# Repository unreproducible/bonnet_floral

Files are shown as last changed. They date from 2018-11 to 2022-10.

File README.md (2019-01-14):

Floral Bonnet

This is an IoT-ish style Bonnet (Hat) intended for a Raspberry Pi Zero based board.

Obviously you can use it on anything with the appropriate header.

Includes:
* BME280 - I2C
* TSL2561 - I2C
* 128x64 OLED Screen - SPI
* RGB LED - 3xGPIO/PWM
* User Button - GPIO
* Serial Port for Kernel Debugging

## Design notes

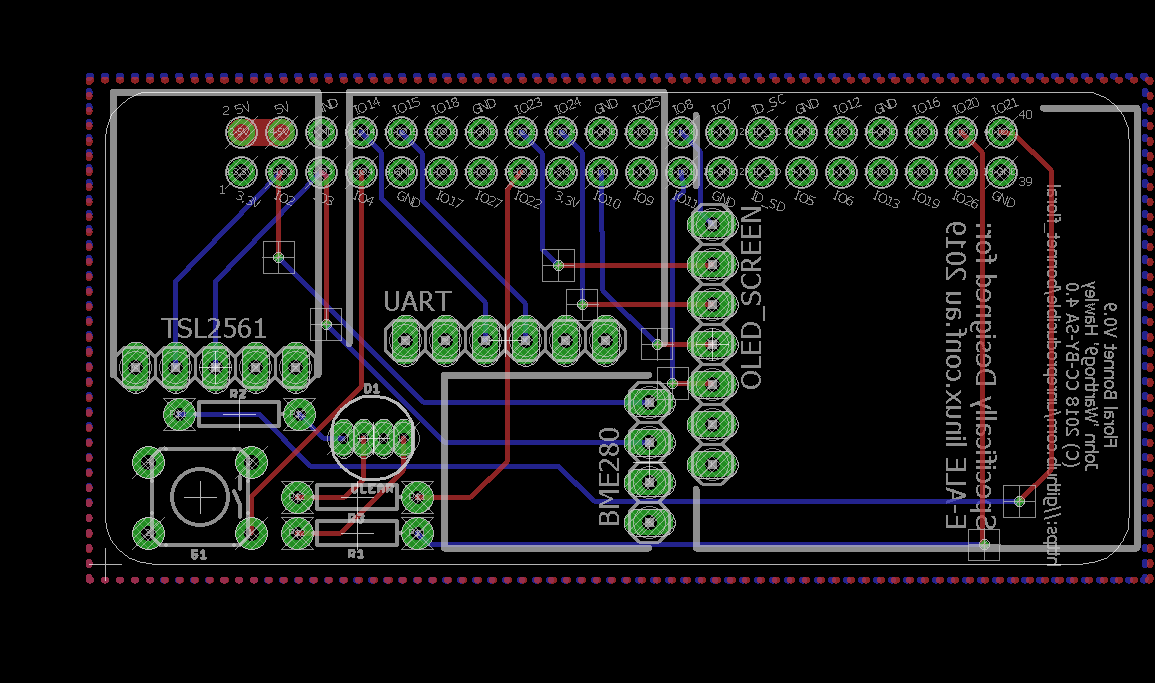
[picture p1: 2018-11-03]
bonnet_floral.png

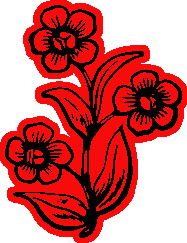
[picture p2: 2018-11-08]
artwork/floral.bmp

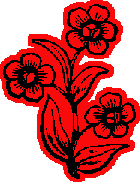
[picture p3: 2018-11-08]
artwork/floral_mirror_smaller.bmp

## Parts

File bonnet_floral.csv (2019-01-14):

Part | Qty | Value | Device | Package | Description | PROD_ID | SF_SKU | VALUE | Expected Cost | Link to example:
BME280 | 1 |  | BME280 subassembly | BME280 subassembly | BME280 subassembly |  |  |  | $4.50 | https://www.alibaba.com/product-detail/3In1-BME280-Digital-Temperature-Humidity-Barometric_60760099302.html
D1 | 1 | CLEAR | LED-RGB-CCCLEAR | LED-RGB-THRU@1 | LED-RGB Common Cathode | DIO-08418 |  | CLEAR | 1.02 | https://www.digikey.com/product-detail/en/inolux/HV-5RGB25/1830-1015-ND/7604615
IC1 |  | RASPBERRY_PI_ZERO_W_(V1.3)-WOUT-RUNTVNOMOUNT | RASPBERRY_PI_ZERO_W_(V1.3)-WOUT-RUNTVNOMOUNT | RASPBERRYPIZEROWV13-WOUT-RUNTV-NOMOUNT | Raspberry Pi Zero W (v1.3) Single-board Computers (installed on back of board) |  |  |  | 1.15 | https://www.digikey.com/product-detail/en/sullins-connector-solutions/SFH11-PBPC-D10-ST-BK/S9197-ND/1990090
OLED_SCREEN |  |  | 0.96in SPI OLED subassembly | 0.96in SPI OLED subassembly | 0.96in SPI OLED subassembly |  |  |  | 3.48 | https://www.alibaba.com/product-detail/SPI-IIC-interface-SSD1306-micro-oled_60581789872.html
R1 |  |  | RESISTORAXIAL-0.3 – 100 Ohm | AXIAL-0.3 | Generic Resistor Package |  |  |  | $0.01 | Note: Whatever is close, and cheap is fine (120Ohm would work)
R2 |  |  | RESISTORAXIAL-0.3 – 150 Ohm | AXIAL-0.3 | Generic Resistor Package |  |  |  | $0.01 | Note: Whatever is close, and cheap is fine (200Ohm would work)
R3 |  |  | RESISTORAXIAL-0.3 – 150 Ohm | AXIAL-0.3 | Generic Resistor Package |  |  |  | $0.01 | Note: Whatever is close, and cheap is fine (200Ohm would work)
S1 |  | MOMENTARY-SWITCH-SPST-PTH-6.0MM | MOMENTARY-SWITCH-SPST-PTH-6.0MM | TACTILE_SWITCH_PTH_6.0MM | Momentary Switch (Pushbutton) - SPST | SWCH-08441 | COM-00097 |  | 0.11 | https://www.digikey.com/product-detail/en/te-connectivity-alcoswitch-switches/1825910-6/450-1650-ND/1632536
TSL2561 |  |  | TSL2561 subassembly | TSL2561 subassembly | TSL2561 subassembly |  |  |  | 1.1 | https://www.alibaba.com/product-detail/GY-2561-TSL2561-Light-Intensity-Luminosity_60419642969.html?s=p
UART |  |  | CP2102 subassembly | CP2102 subassembly | CP2102 subassembly |  |  |  | 1.01 | https://www.alibaba.com/product-detail/6Pin-Serial-Converter-UART-STC-CP2102_60768471247.html?s=p
 |  |  |  |  |  |  | Total per board (parts): |  | 12.40708
 |  |  |  |  |  |  | Rough assembly costs: |  | 3.8
 |  |  |  |  |  |  | Shipping to US |  | 0.32
 |  |  |  |  |  |  | Rough total cost: |  | 16.52708

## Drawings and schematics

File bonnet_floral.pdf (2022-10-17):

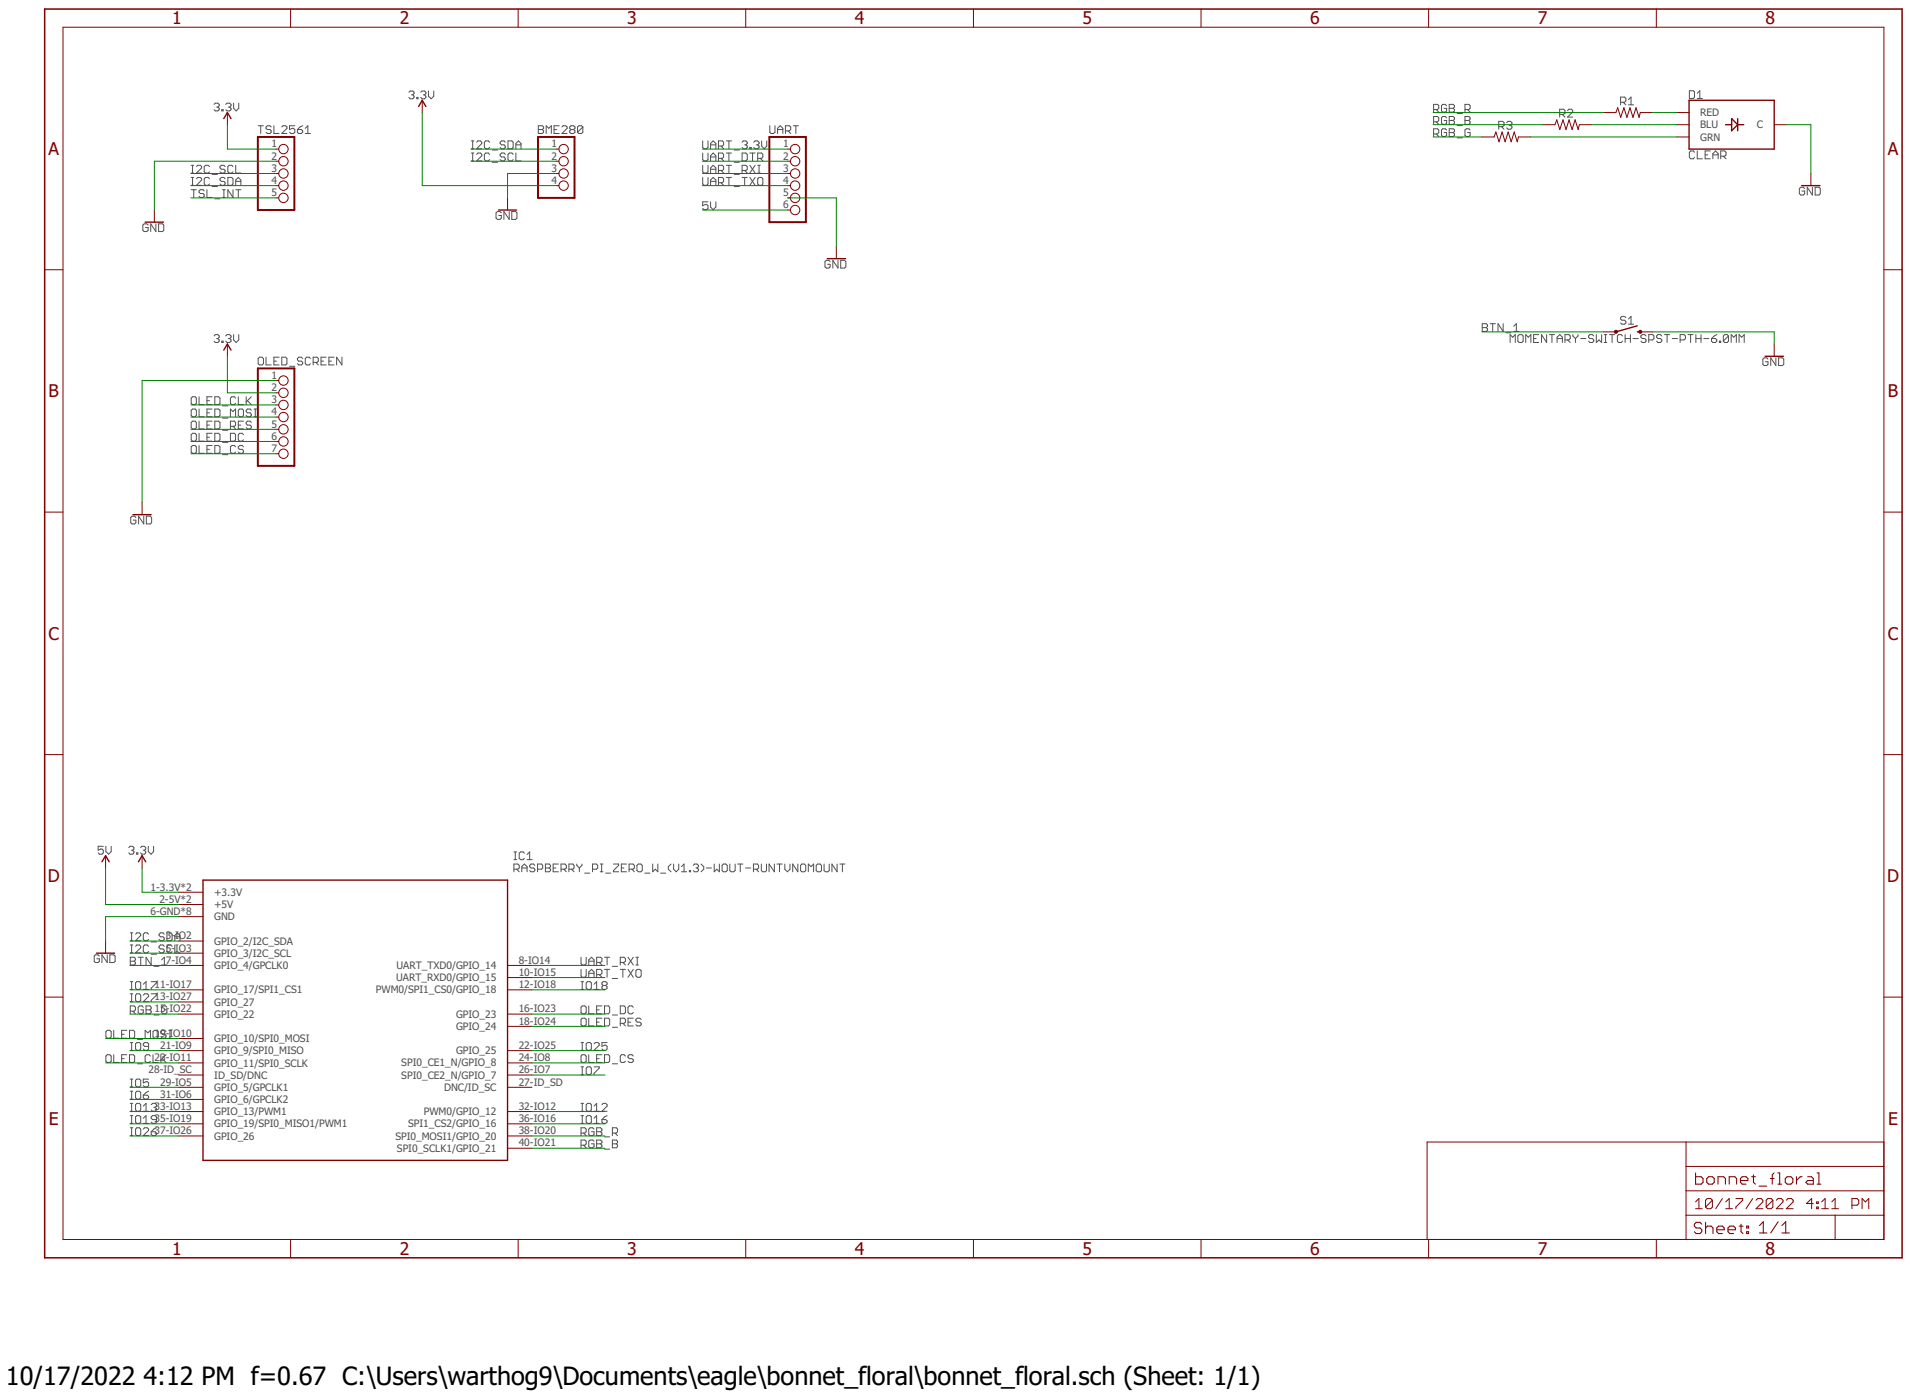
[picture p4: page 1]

10/17/2022 4:12 PM f=0.67 C:\Users\warthog9\Documents\eagle\bonnet_floral\bonnet_floral.sch (Sheet: 1/1)

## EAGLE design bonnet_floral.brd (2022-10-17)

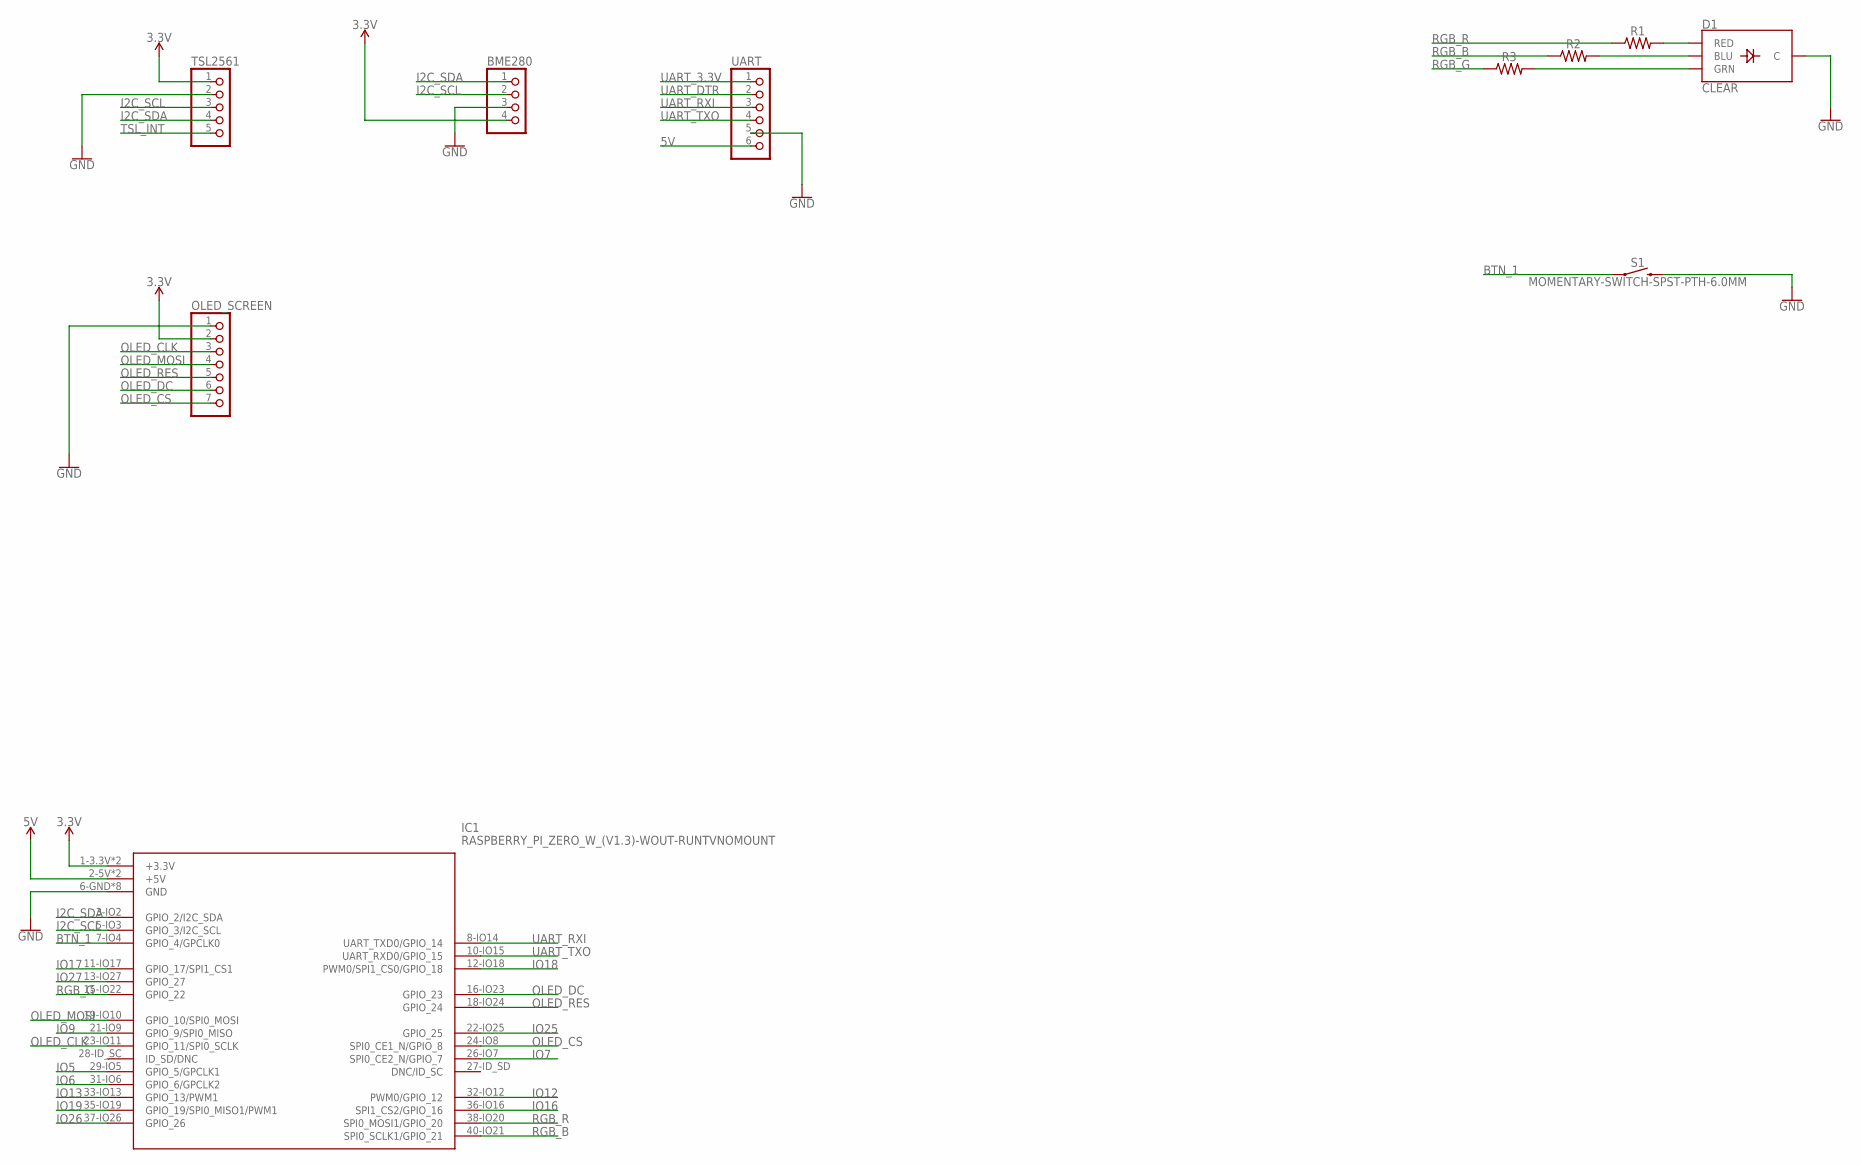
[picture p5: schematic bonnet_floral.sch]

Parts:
BME280: PINHD-1X4; 1X04
D1: CLEAR; LED-RGB-THRU@1
IC1: RASPBERRY_PI_ZERO_W_(V1.3)-WOUT-RUNTVNOMOUNT; RASPBERRYPIZEROWV13-WOUT-RUNTV-NOMOUNT
OLED_SCREEN: PINHD-1X7; 1X07
R1, R2, R3: AXIAL-0.3
S1: MOMENTARY-SWITCH-SPST-PTH-6.0MM; TACTILE_SWITCH_PTH_6.0MM
TSL2561: PINHD-1X5; 1X05
UART: PINHD-1X6; 1X06

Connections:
3.3V: BME280.4, IC1.1-3.3V (+3.3V), IC1.17-3.3V (+3.3V), OLED_SCREEN.2, TSL2561.1
5V: IC1.2-5V (+5V), IC1.4-5V (+5V), UART.6
BTN_1: IC1.7-IO4 (GPIO_4/GPCLK0), S1.1
GND: BME280.3, D1.2 (C), IC1.6-GND (GND), IC1.9-GND (GND), IC1.14-GND (GND), IC1.20-GND (GND), IC1.25-GND (GND), IC1.30-GND (GND), IC1.34-GND (GND), IC1.39-GND (GND), OLED_SCREEN.1, S1.3 (2), TSL2561.2, UART.5
I2C_SCL: BME280.2, IC1.5-IO3 (GPIO_3/I2C_SCL), TSL2561.3
I2C_SDA: BME280.1, IC1.3-IO2 (GPIO_2/I2C_SDA), TSL2561.4
IO5: IC1.29-IO5 (GPIO_5/GPCLK1)
IO6: IC1.31-IO6 (GPIO_6/GPCLK2)
IO7: IC1.26-IO7 (SPI0_CE2_N/GPIO_7)
IO9: IC1.21-IO9 (GPIO_9/SPI0_MISO)
IO12: IC1.32-IO12 (PWM0/GPIO_12)
IO13: IC1.33-IO13 (GPIO_13/PWM1)
IO16: IC1.36-IO16 (SPI1_CS2/GPIO_16)
IO17: IC1.11-IO17 (GPIO_17/SPI1_CS1)
IO18: IC1.12-IO18 (PWM0/SPI1_CS0/GPIO_18)
IO19: IC1.35-IO19 (GPIO_19/SPI0_MISO1/PWM1)
IO25: IC1.22-IO25 (GPIO_25)
IO26: IC1.37-IO26 (GPIO_26)
IO27: IC1.13-IO27 (GPIO_27)
unnamed: D1.1 (RED), R1.P$2 (2)
unnamed: D1.4 (BLU), R2.P$2 (2)
unnamed: D1.3 (GRN), R3.P$2 (2)
OLED_CLK: IC1.23-IO11 (GPIO_11/SPI0_SCLK), OLED_SCREEN.3
OLED_CS: IC1.24-IO8 (SPI0_CE1_N/GPIO_8), OLED_SCREEN.7
OLED_DC: IC1.16-IO23 (GPIO_23), OLED_SCREEN.6
OLED_MOSI: IC1.19-IO10 (GPIO_10/SPI0_MOSI), OLED_SCREEN.4
OLED_RES: IC1.18-IO24 (GPIO_24), OLED_SCREEN.5
RGB_B: IC1.40-IO21 (SPI0_SCLK1/GPIO_21), R2.P$1 (1)
RGB_G: IC1.15-IO22 (GPIO_22), R3.P$1 (1)
RGB_R: IC1.38-IO20 (SPI0_MOSI1/GPIO_20), R1.P$1 (1)
TSL_INT: TSL2561.5
UART_3.3V: UART.1
UART_DTR: UART.2
UART_RXI: IC1.8-IO14 (UART_TXD0/GPIO_14), UART.3
UART_TXO: IC1.10-IO15 (UART_RXD0/GPIO_15), UART.4

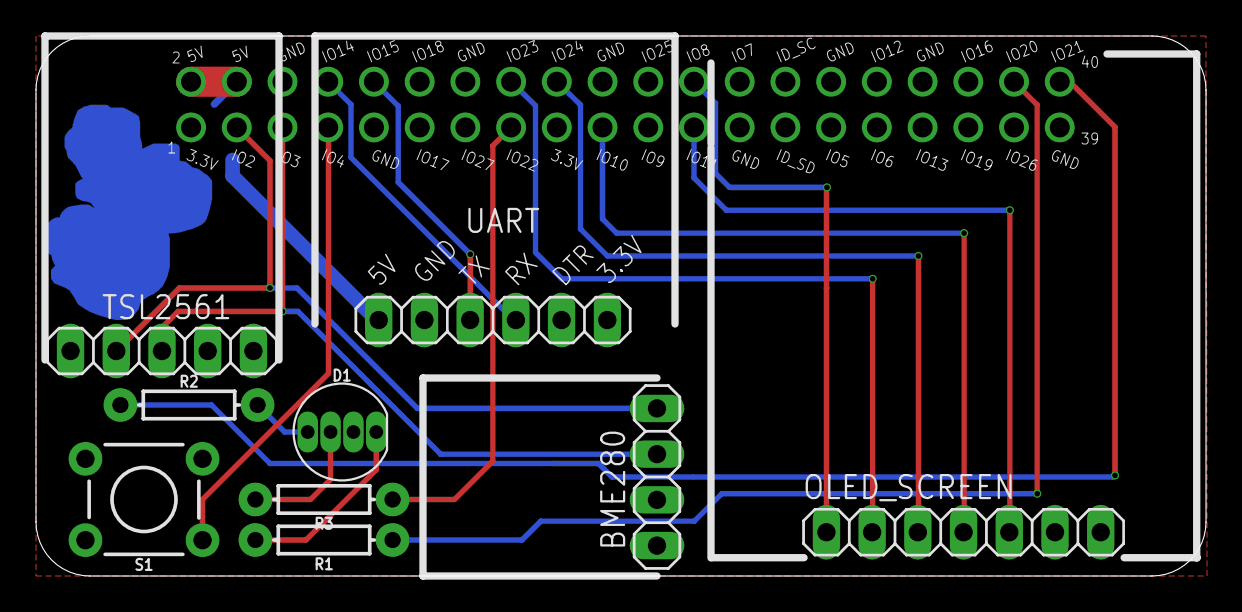
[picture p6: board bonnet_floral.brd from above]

Board: 2 copper layers, 65.0 x 30.0 mm, 11 parts (1 on the bottom side), 19 nets.

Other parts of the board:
U$1: FLORAL_SMALLER_MIRROR

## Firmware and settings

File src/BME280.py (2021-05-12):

# Distributed with a free-will license.
# Use it any way you want, profit or free, provided it fits in the licenses of its associated works.
# BME280
# This code is designed to work with the BME280_I2CS I2C Mini Module available from ControlEverything.com.
# https://www.controleverything.com/content/Humidity?sku=BME280_I2CS#tabs-0-product_tabset-2

# from https://github.com/ControlEverythingCommunity/BME280.git
# minor fixes to adjust for python3

import smbus
import time

# Get I2C bus
bus = smbus.SMBus(1)

# BME280 address, 0x76(118)
# Read data back from 0x88(136), 24 bytes
b1 = bus.read_i2c_block_data(0x76, 0x88, 24)

# Convert the data
# Temp coefficients
dig_T1 = b1[1] * 256 + b1[0]
dig_T2 = b1[3] * 256 + b1[2]
if dig_T2 > 32767 :
    dig_T2 -= 65536
dig_T3 = b1[5] * 256 + b1[4]
if dig_T3 > 32767 :
    dig_T3 -= 65536

# Pressure coefficients
dig_P1 = b1[7] * 256 + b1[6]
dig_P2 = b1[9] * 256 + b1[8]
if dig_P2 > 32767 :
    dig_P2 -= 65536
dig_P3 = b1[11] * 256 + b1[10]
if dig_P3 > 32767 :
    dig_P3 -= 65536
dig_P4 = b1[13] * 256 + b1[12]
if dig_P4 > 32767 :
    dig_P4 -= 65536
dig_P5 = b1[15] * 256 + b1[14]
if dig_P5 > 32767 :
    dig_P5 -= 65536
dig_P6 = b1[17] * 256 + b1[16]
if dig_P6 > 32767 :
    dig_P6 -= 65536
dig_P7 = b1[19] * 256 + b1[18]
if dig_P7 > 32767 :
    dig_P7 -= 65536
dig_P8 = b1[21] * 256 + b1[20]
if dig_P8 > 32767 :
    dig_P8 -= 65536
dig_P9 = b1[23] * 256 + b1[22]
if dig_P9 > 32767 :
    dig_P9 -= 65536

# BME280 address, 0x76(118)
# Read data back from 0xA1(161), 1 byte
dig_H1 = bus.read_byte_data(0x76, 0xA1)

# BME280 address, 0x76(118)
# Read data back from 0xE1(225), 7 bytes
b1 = bus.read_i2c_block_data(0x76, 0xE1, 7)

# Convert the data
# Humidity coefficients
dig_H2 = b1[1] * 256 + b1[0]
if dig_H2 > 32767 :
    dig_H2 -= 65536
dig_H3 = (b1[2] &  0xFF)
dig_H4 = (b1[3] * 16) + (b1[4] & 0xF)
if dig_H4 > 32767 :
    dig_H4 -= 65536
dig_H5 = (b1[4] / 16) + (b1[5] * 16)
if dig_H5 > 32767 :
    dig_H5 -= 65536
dig_H6 = b1[6]
if dig_H6 > 127 :
    dig_H6 -= 256

# BME280 address, 0x76(118)
# Select control humidity register, 0xF2(242)
#		0x01(01)	Humidity Oversampling = 1
bus.write_byte_data(0x76, 0xF2, 0x01)
# BME280 address, 0x76(118)
# Select Control measurement register, 0xF4(244)
#		0x27(39)	Pressure and Temperature Oversampling rate = 1
#					Normal mode
bus.write_byte_data(0x76, 0xF4, 0x27)
# BME280 address, 0x76(118)
# Select Configuration register, 0xF5(245)
#		0xA0(00)	Stand_by time = 1000 ms
bus.write_byte_data(0x76, 0xF5, 0xA0)

time.sleep(0.5)

# BME280 address, 0x76(118)
# Read data back from 0xF7(247), 8 bytes
# Pressure MSB, Pressure LSB, Pressure xLSB, Temperature MSB, Temperature LSB
# Temperature xLSB, Humidity MSB, Humidity LSB
data = bus.read_i2c_block_data(0x76, 0xF7, 8)

# Convert pressure and temperature data to 19-bits
adc_p = ((data[0] * 65536) + (data[1] * 256) + (data[2] & 0xF0)) / 16
adc_t = ((data[3] * 65536) + (data[4] * 256) + (data[5] & 0xF0)) / 16

# Convert the humidity data
adc_h = data[6] * 256 + data[7]

# Temperature offset calculations
var1 = ((adc_t) / 16384.0 - (dig_T1) / 1024.0) * (dig_T2)
var2 = (((adc_t) / 131072.0 - (dig_T1) / 8192.0) * ((adc_t)/131072.0 - (dig_T1)/8192.0)) * (dig_T3)
t_fine = (var1 + var2)
cTemp = (var1 + var2) / 5120.0
fTemp = cTemp * 1.8 + 32

# Pressure offset calculations
var1 = (t_fine / 2.0) - 64000.0
var2 = var1 * var1 * (dig_P6) / 32768.0
var2 = var2 + var1 * (dig_P5) * 2.0
var2 = (var2 / 4.0) + ((dig_P4) * 65536.0)
var1 = ((dig_P3) * var1 * var1 / 524288.0 + ( dig_P2) * var1) / 524288.0
var1 = (1.0 + var1 / 32768.0) * (dig_P1)
p = 1048576.0 - adc_p
p = (p - (var2 / 4096.0)) * 6250.0 / var1
var1 = (dig_P9) * p * p / 2147483648.0
var2 = p * (dig_P8) / 32768.0
pressure = (p + (var1 + var2 + (dig_P7)) / 16.0) / 100

# Humidity offset calculations
var_H = ((t_fine) - 76800.0)
var_H = (adc_h - (dig_H4 * 64.0 + dig_H5 / 16384.0 * var_H)) * (dig_H2 / 65536.0 * (1.0 + dig_H6 / 67108864.0 * var_H * (1.0 + dig_H3 / 67108864.0 * var_H)))
humidity = var_H * (1.0 -  dig_H1 * var_H / 524288.0)
if humidity > 100.0 :
    humidity = 100.0
elif humidity < 0.0 :
    humidity = 0.0

# Output data to screen
print("Temperature in Celsius : %.2f C" %cTemp)
print("Temperature in Fahrenheit : %.2f F" %fTemp)
print("Pressure : %.2f hPa " %pressure)
print("Relative Humidity : %.2f %%" %humidity)

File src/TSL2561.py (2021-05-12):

# Distributed with a free-will license.
# Use it any way you want, profit or free, provided it fits in the licenses of its associated works.
# TSL2561
# This code is designed to work with the TSL2561_I2CS I2C Mini Module available from ControlEverything.com.
# https://www.controleverything.com/content/Light?sku=TSL2561_I2CS#tabs-0-product_tabset-2

# gotten from https://github.com/ControlEverythingCommunity/TSL2561.git
# minor changes to make it work with python3

import smbus
import time

# Get I2C bus
bus = smbus.SMBus(1)

# TSL2561 address, 0x39(57)
# Select control register, 0x00(00) with command register, 0x80(128)
#		0x03(03)	Power ON mode
bus.write_byte_data(0x39, 0x00 | 0x80, 0x03)
# TSL2561 address, 0x39(57)
# Select timing register, 0x01(01) with command register, 0x80(128)
#		0x02(02)	Nominal integration time = 402ms
bus.write_byte_data(0x39, 0x01 | 0x80, 0x02)

time.sleep(0.5)

# Read data back from 0x0C(12) with command register, 0x80(128), 2 bytes
# ch0 LSB, ch0 MSB
data = bus.read_i2c_block_data(0x39, 0x0C | 0x80, 2)

# Read data back from 0x0E(14) with command register, 0x80(128), 2 bytes
# ch1 LSB, ch1 MSB
data1 = bus.read_i2c_block_data(0x39, 0x0E | 0x80, 2)

# Convert the data
ch0 = data[1] * 256 + data[0]
ch1 = data1[1] * 256 + data1[0]

# Output data to screen
print("Full Spectrum(IR + Visible) :%d lux" %ch0)
print("Infrared Value :%d lux" %ch1)
print("Visible Value :%d lux" %(ch0 - ch1))

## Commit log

2018-11-03 Initial Commit - Basic Board Template
2018-11-03 Adding V0.9 of the Floral Bonnet
    This completes all the major pieces, it's rough but basically
    ready to be shipped out for prototyping
    [bonnet_floral.brd, bonnet_floral.sch]
2018-11-03 Adding Schematic PDF and board image
2018-11-03 Adding Prototype (v0.9) gerbers
    [bonnet_floral.drills.xln]
2018-11-06 UART was rotate 180deg the wrong direction. Rotated correctly
    I've added pinout information for it as well so it's slightly
    more obvious what's going on
    [bonnet_floral.brd]
2018-11-07 Reving the board version number to 0.9.1
    This is a bugfix version release, the changes aren't finalized
    but figured reving the version now would mean it's done when we
    run the next set of prototypes
    [bonnet_floral.brd]
2018-11-08 Moving the BME280 down a little
    The BME280 was right up against the lower side of the CP2102, so
    I'm moving it down 1mm (and re-routing the signals as needed) to
    give it a little bit of space.
    [bonnet_floral.brd]
2018-11-08 Adjusting the back silkscreen, adding artwork to board
    Also cleaning up the DRC checks from before
    removing https:// from the board url to make it bigger
    [bonnet_floral.brd]
2018-11-08 Committing Gerbers v0.9.1 - bugfix release, tagging
    [bonnet_floral.drills.xln]
2019-01-14 Adding the last of the production materials
    These are mostly used if you are going to do a full production run
    of the bonnets. That being said they may be found useful to someone
    who is doing their own assembly as well.
    [bonnet_floral.csv, bonnet_floral.xls, bonnet_floral_centroid.csv]
2021-05-08 Moving the Gerbers zip around so it's easier to distinguish
2021-05-08 Adjusting silkscreen post LCA
    So this is basically going to open it up for general usage. I'm
    going to keep the original v0.9.1 as "special" for LCA 2019, and
    not continue with that identifier in v1.0 (the changes are purely
    cosmetic)
    [bonnet_floral.brd]
2021-05-08 Updating gerbers, revving to version v1.0
2021-05-12 Add starlight commands & BME280 & TSL2561 driver
    This pulls in the drivers for the BME280 and the TSL2561 directly
    instead of relying on the upstream location, particularly since they
    haven't been updated since 2018, and the license is compatible here.
    This also adds in basic commands to get everything working on the
    BeagleV Starlight board which has a compatible 2x20 pin header.
    Currently the luma examples are disabled as trying to get the SSD1306
    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
2022-10-17 Add Serial Port 5V power feed
    So in the original design the power coming from the serial port header
    was intentionally left N/C, however there's argument that this might
    have made some learning applications more complicated / expensive.
    Attaching it to the main PI header 5V looks like it should work, and
    feed into the same 5V linke the normal power header does. Since the 5V
    coming from the serial port chip seems to also feed directly from the
    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
    [bonnet_floral.brd, bonnet_floral.sch]
2022-10-17 Rotate oled screen 90deg counter-clockwise
    This is basically a manufacturing optimization to move the under side
    components of the oled screen away from the pi header. There's a cap
    that comes a bit close to the header and it's troublesome. This shifts
    the screen around and allows for just some kapton tape on the oled
    screen to alleviate any possible touching / arcing.
    [bonnet_floral.brd]
2022-10-17 Rev board to v1.1
    [bonnet_floral.brd]
2022-10-17 Rev schematic to v1.1
2022-10-17 Gerbers: update to v1.1
    [bonnet_floral.drills.xln]

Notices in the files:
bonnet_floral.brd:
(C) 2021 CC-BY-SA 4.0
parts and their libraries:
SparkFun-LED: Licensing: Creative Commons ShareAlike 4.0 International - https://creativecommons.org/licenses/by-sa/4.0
